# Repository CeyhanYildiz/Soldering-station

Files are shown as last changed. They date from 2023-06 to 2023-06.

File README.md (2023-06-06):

# My First Ever Self-Built Soldering Station

Presenting my inaugural creation: the self-built Soldering Station—a testament to my passion and determination.

## Features

- Meticulously assembled with top-quality components
- Seamlessly blends functionality and aesthetics
- Ergonomic handle for a comfortable grip
- Sleek control panel for intuitive operation
- State-of-the-art heating element for rapid and precise temperature control
- Integrated smart sensor system for safety and protection of delicate components

## Usage

Using this self-built soldering station fills me with immense satisfaction. It represents my commitment to craftsmanship and the pursuit of excellence.

## Journey and Inspiration

With my first creation, I have evolved from a novice to an artisan. This soldering station embodies innovation and creativity, empowering me to bring remarkable projects to life.

The journey has just begun, and I eagerly anticipate the countless achievements this exceptional tool will enable.

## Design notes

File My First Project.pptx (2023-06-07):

## My First Project : The Soldering Station

Ceyhan Yildiz

## Soldering Station : What to expect

1.0

Why this Project
Functionality
PCB
Case
Best Moments
Worst Moments
Cost

## Why this Project

2.0

Simplifying Complexity
Learning from Others

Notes: Simplifying Complexity : We mochten kiezen, Hard Time S1
Learning from Others : Same Project For exempel True is beter than SMD

## functionality

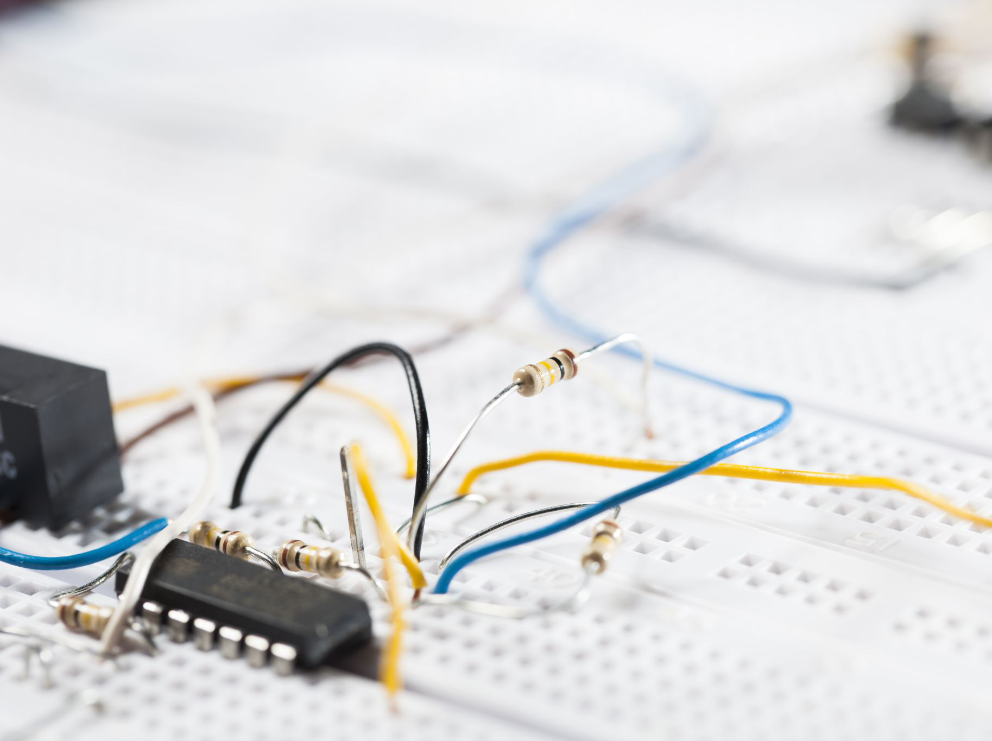
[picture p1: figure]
Electronics protoboard

- Soldering Iron
  - Components to be Soldered
- Power Supply Unit
- Temperature Control Mechanism

3.0

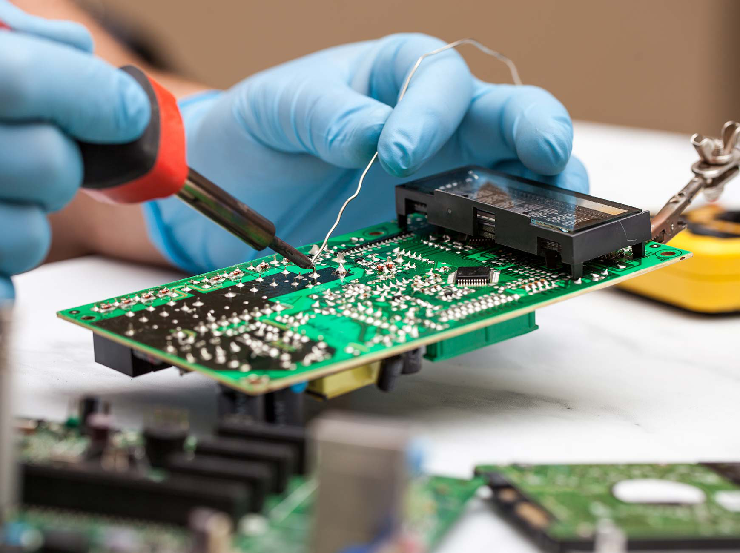
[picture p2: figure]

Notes: Soldering Iron:
Illustration of a soldering iron with a metal tip.
Components to be Soldered:
Small electronic components, such as resistors or capacitors, represented by symbols or icons.
Connection lines between the components.
Power Supply Unit:
Box representing the power supply unit.
Temperature Control Mechanism:
Rotary knob
Connection lines linking the temperature control mechanism to the soldering iron.
Soldering Process:
Illustration of the soldering iron touching the component leads and the circuit board.
Heat waves emanating from the soldering iron to indicate the heating process.
Melting solder represented by droplets or lines bonding the component leads and the circuit board.
Result:
Illustration of a completed solder joint with the components securely connected to the circuit board.

## PCB

- Schematics
  - Thermokoppel
  - Voeding
  - CPY
  - PBM
  - Display
- Manufactory
- Soldering

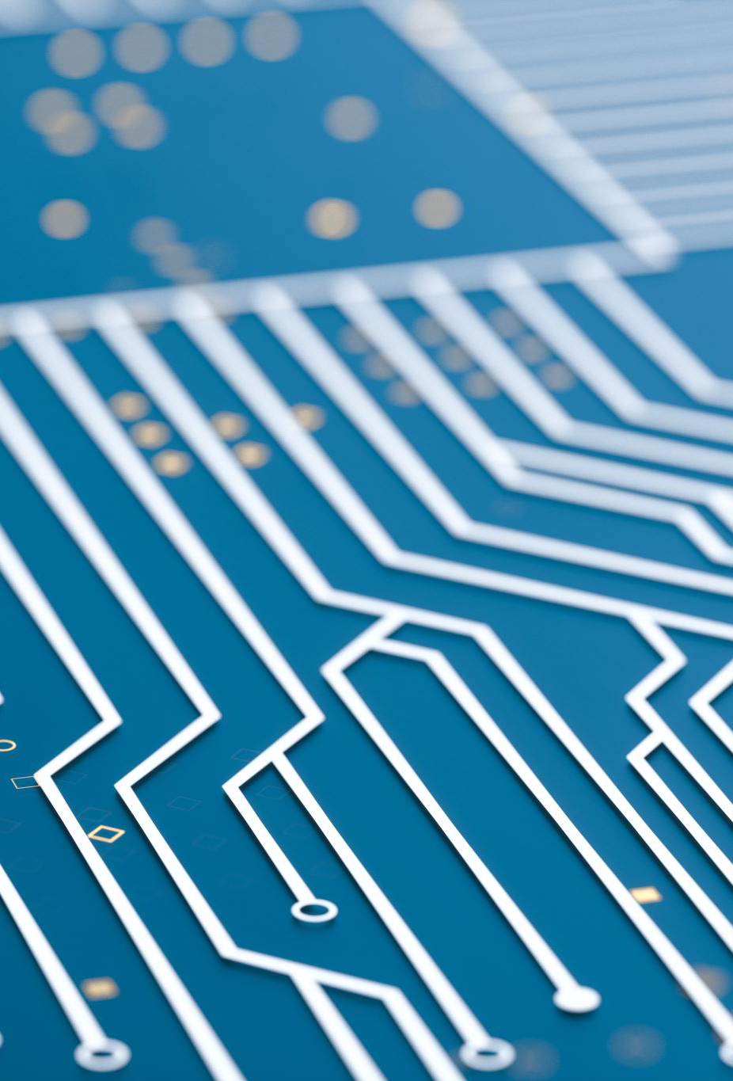
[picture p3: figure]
Een blauwe printplaat

4.0

## case design

5.0

Version 0.1

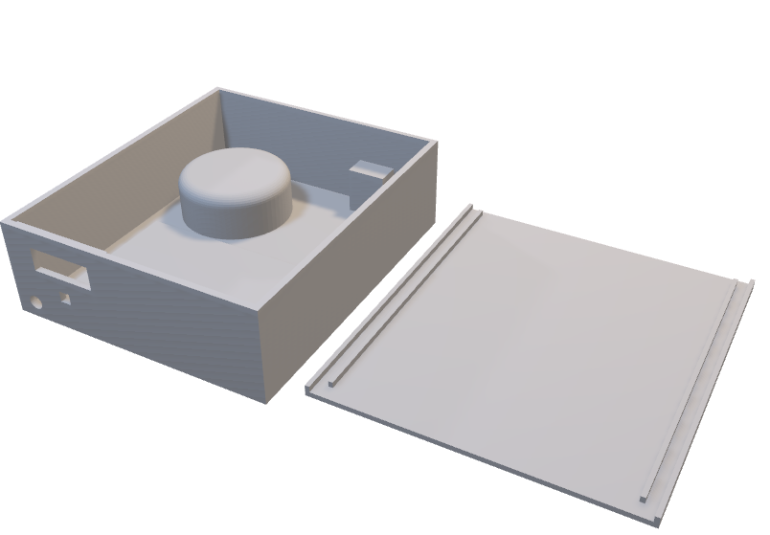
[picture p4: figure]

Version 0.0

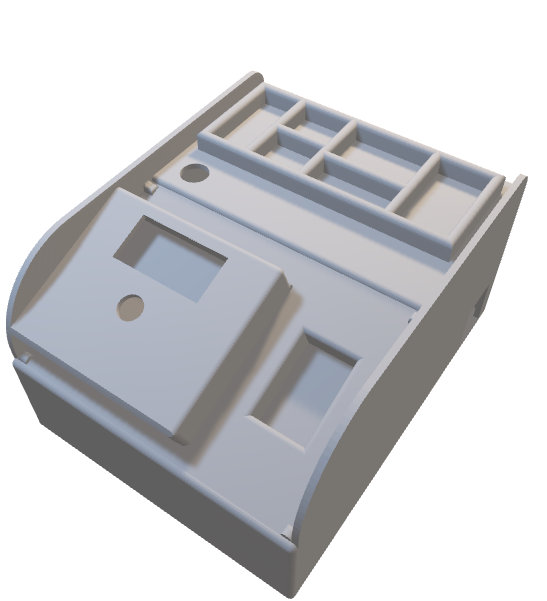
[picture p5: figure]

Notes: Lost hope
Did not gave up

## Best Moments

6.0

Learned
Ready for the NEXT

## Worst Moments

7.0

Price
Silkscreen
Timing
Learning
Incomplete

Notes: Not knowing the correct Prices
Silkscreen to small
pcb took to long to arrivé
Learing curve Altium Designer
Not done

## Cost Breakdown

- Components : €35
- PCB : €32
- Toroidal transformer : €25 – €40
Extra :
  - Display : €1,60
  - Case : €25
  - Soldering iron : €15
Total : €133,6 – €148,6

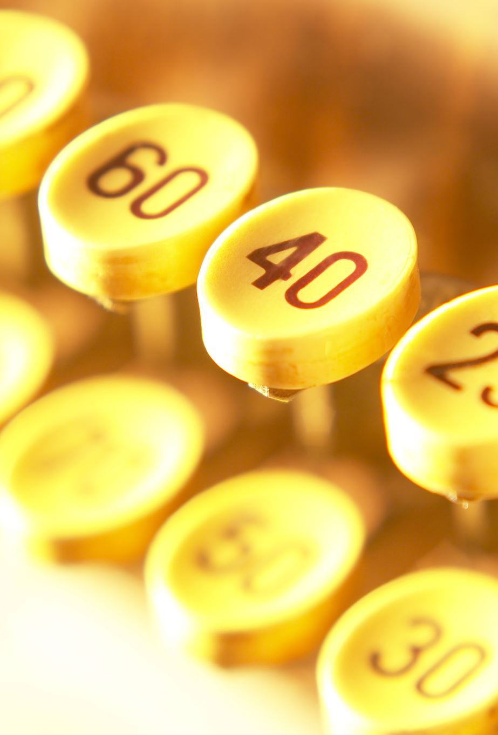
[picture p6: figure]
Antique cash register keys

8.0

## THANKS for your attentions

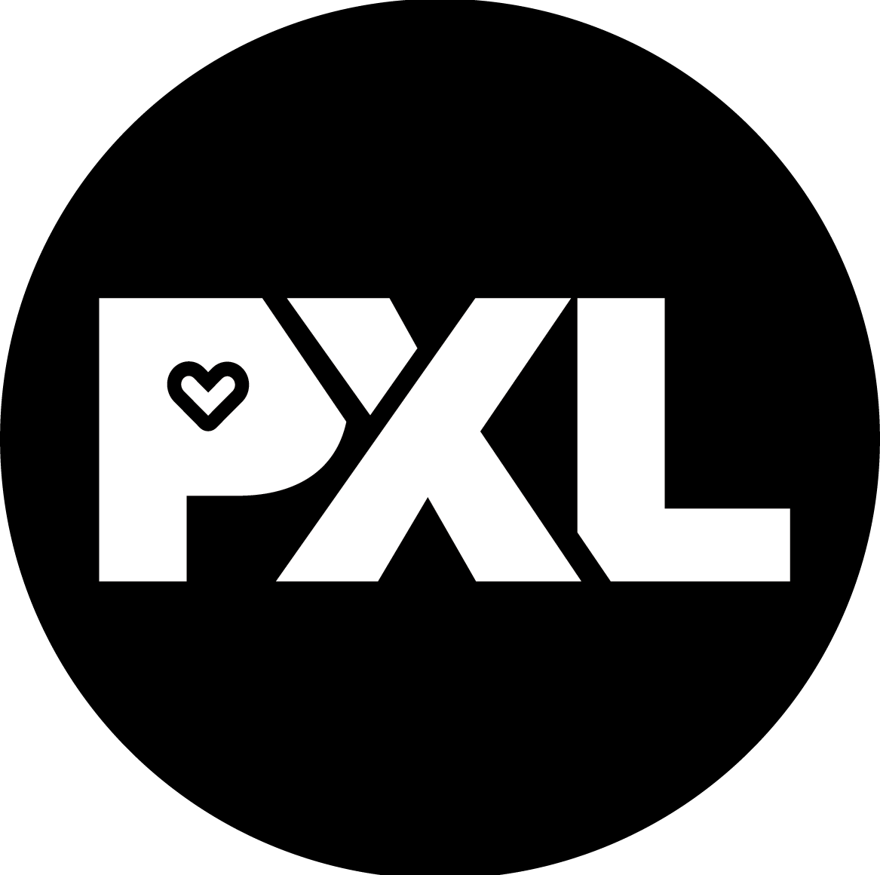
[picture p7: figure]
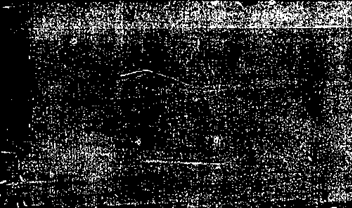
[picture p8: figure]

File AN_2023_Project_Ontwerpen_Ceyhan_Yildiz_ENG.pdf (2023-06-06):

# ELEKTRONICA-ICT

### Project Ontwerpen

# Soldering Station

Author Ceyhan Yildiz

## Content

ELECTRONICS-ICT | Project Design 2020-2021

## 1 Introduction

For my project I embarked on building a soldering station based on the blueprint provided by our lecturer ( Elektor ( ElektorMAG, 2021) ). The soldering station I created includes essential features such as a temperature control knob, soldering iron holder and a replaceable tip iron. These components enable precise temperature control during soldering tasks and provide a safe storage solution for the soldering iron.

While I consider my efforts in building the soldering station satisfactory. I do recognize that there is room for improvement. One aspect I identified for enhancement is the addition of a built-in smoke absorber for safety purposes. Implementing such a feature would help mitigate potential health risks associated with soldering fumes.

However, due to financial constraints, I was unable to fully complete the project as envisioned. Despite this limitation. I was able to gain valuable hands-on experience and expand my knowledge in soldering techniques and electronics assembly. Building a functional device from scratch was challenging but ultimately provided me with a deeper understanding of the entire process.

In conclusion, even though I didn't have sufficient funds to fully realize my project. I’m satisfied with the progress I made in constructing the soldering station. I now possess a valuable tool for future DIY (Do It Yourself) projects and have acquired valuable skills and knowledge along the way. Moving forward, I hope to continue improving my soldering station and explore additional projects in the field of electronics.

## 2 Material and methods

I consider myself quite lucky as one of my college mates made it incredibly easy for me to acquire the necessary components for a mere 35 euros. This stroke of fortune has paved the way for an exciting project or experiment. Let me introduce you to the components I now possess:

Resistors:

- 18 KΩ smd 805
- 1 MΩ smd 805
- 68 KΩ smd 805
- 5.6 KΩ smd 805
- 10 KΩ smd 805
- 100 Ω smd 805
- 10 MΩ smd 805
- 4.7 KΩ smd 805

Inductors:

- | L1 | smd 805
- | L2 | smd 2545

Capacitors:

- 4700 µF True hole D25xL25mm
- 10 µF smd D4XL5,4
- 100 nF | smd 805
- 100 µF | smd D8xL10mm
- 10 nF smd 805

Semiconductors:

- | 1N4007 | smd SOD-123Fl
- | Zener | smd SOD-123Fl
- | 1N14148 | smd SOD-123Fl
- | Bridge | smd TTF
- | BC847C | smd SOT-23
- | MOSFET-P | smd TO-252-2(DPAK)
- | BC857C | SOT-23
- | DC/DC | True hole
- MCP6002-E/MS MSOP-8
- Microcontroller TQFP-48
- | Relay | True hole
- IC2 7-segment smd SOP-20
- | Encoder | True hole

Please note that the following comments can also be found in the ElektorMAG magazine published in 2021 on page 34.

Smd ( Surface mount technology )

SOD ( Small Outline Diode )

TO ( Transistor Outline )

With these components, I can construct the soldering station that meets my specific needs. The resistors will help regulate lower the voltage, and the capacitors and inductors can assist with filtering and power supply stability. The semiconductors, including diodes and transistors, play crucial roles in controlling the heating element and managing the power flow.

The microcontroller will serve as the brain of the soldering station, enabling precise temperature control, user interface, and additional features such as temperature display and adjustable settings. The relay can be used for switching the heating element on and off, while the IC2 7-segment display driver will allow for temperature readout.

Overall, with these components, I have the foundation for building a functional and customized soldering station that will enhance my soldering projects with precise temperature control and additional features.

### 2.1 Flowchart

Below is a comprehensive flowchart outlining the sequential process for creating a project using Altium Designer. It encompasses the stages of case design and printing, PCB soldering, testing, and project assembly. This streamlined workflow offers a clear, step-by-step guide to ensure a successful project completion.

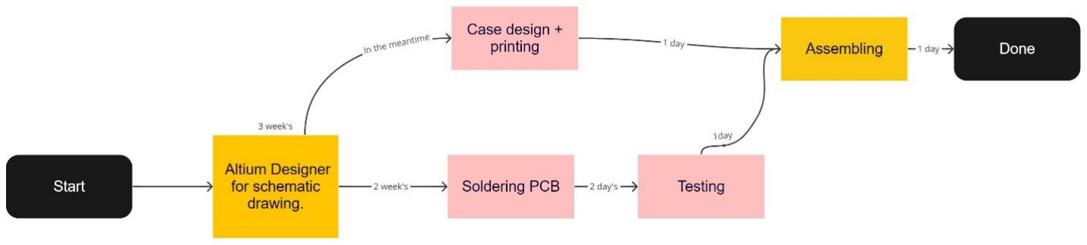
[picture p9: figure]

The process begins with the utilization of Altium Designer. A software tool for schematic drawing which is used for a duration of 3 weeks. During this time the schematic design for the PCB is meticulously created.

After successfully finalizing the schematic design I decided to collaborate with two other individuals who were also working on the same project. By combining our efforts and orders, we were able to leverage the benefits of a group purchase resulting in reduced shipping costs. As a result I only needed to pay 32 euros, significantly reducing the overall expenses.

During the waiting period of approximately two weeks for the PCB fabrication. I made efficient use of my time by focusing on designing and printing a customized case for the project. This approach allowed me to create a personalized case that perfectly matched the project's requirements ensuring both functionality and aesthetics were met. By capitalizing on this waiting period I ensured that every aspect of the project was optimized and met my high standards.

Once the PCB arrives from the manufacturer the next step is soldering. This involves carefully placing and soldering electronic components onto the PCB following the schematic design. Precision and attention to detail are vital during this phase.

Following the soldering process a dedicated 2-day period is allocated for testing the functionality of the assembled PCB. Various tests and inspections are conducted to ensure that the PCB operates as intended and meets the required specifications.

Once the PCB has successfully passed the testing phase the final step is assembling the project. The assembled PCB along with any other necessary components is integrated into the previously printed case.

### 2.2 Observed

During the construction of my project. I observed that certain students opted for a greater utilization of through-hole components as opposed to SMD’s. This strategic decision allowed them to assemble the PCB more effortlessly. In contrast, I encountered difficulties while attempting to incorporate a silkscreen onto my PCB design.

## 3 Results

Despite facing financial constraints, I managed to make significant progress on the project. I successfully soldered my PCB, demonstrating my skill and attention to detail in electronic circuitry. By meticulously assembling and connecting the components, I ensured the functionality and reliability of the PCB.

Regarding the 3D design, although I couldn't afford to print it, I dedicated my efforts to carefully drawing and refining the design. Paying attention to intricate details, I aimed to create an accurate representation of the envisioned object or prototype. While the physical manifestation was limited by financial circumstances, my commitment to the project is evident through the meticulous and thorough work put into the 3D design.

### 3.1 Case

During the course of my project, there came a pivotal moment when I confronted a disheartening realization: my existing design fell short of my lofty expectations. Rather than succumbing to discouragement, I chose to embrace the challenge head-on, harnessing my unwavering determination to create a remarkably enhanced 3D design. Refusing to be deterred by self-doubt, I swiftly crafted a brand-new case design, propelling myself beyond my previous endeavors and embarking on a relentless pursuit of an ideal outcome.

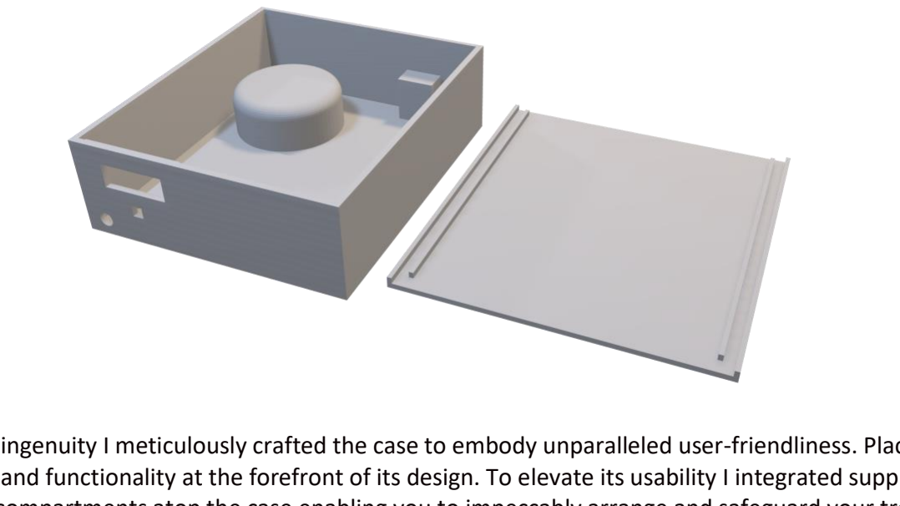
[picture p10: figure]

With utmost ingenuity I meticulously crafted the case to embody unparalleled user-friendliness. Placing convenience and functionality at the forefront of its design. To elevate its usability I integrated supplementary storage compartments atop the case enabling you to impeccably arrange and safeguard your treasured keepsakes. Moreover I attentively incorporated a compact holder specifically tailored to securely accommodate a sponge Providing you with effortless access to maintain the cleanliness of your soldering tip whenever the need arises. Through the implementation of these considerate features my intention was to guarantee a seamless and gratifying user experience for anyone utilizing the case.

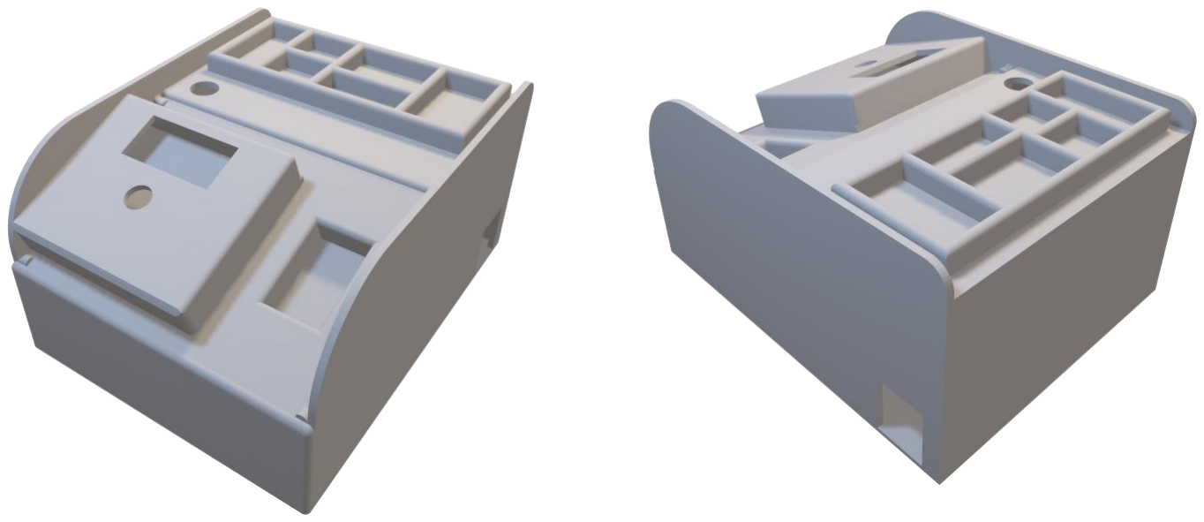
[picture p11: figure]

### 3.2 PCB

I am genuinely overjoyed with the final result of the PCB design. The meticulous attention to detail and careful consideration of every aspect have culminated in a truly remarkable outcome. One aspect that brings me immense satisfaction is the choice of color. The selected color not only adds a touch of elegance but also enhances the overall visual appeal of the board. Its subtle yet distinct presence exudes a sense of professionalism and sophistication elevating the board to a new level of aesthetic excellence. It brings me great pleasure to see that the design meets and even surpasses my expectations, a testament to the dedication and effort invested in this project. I am confident that this exceptional visual appeal will captivate the attention of anyone who encounters the PCB leaving a lasting impression of quality and craftsmanship.

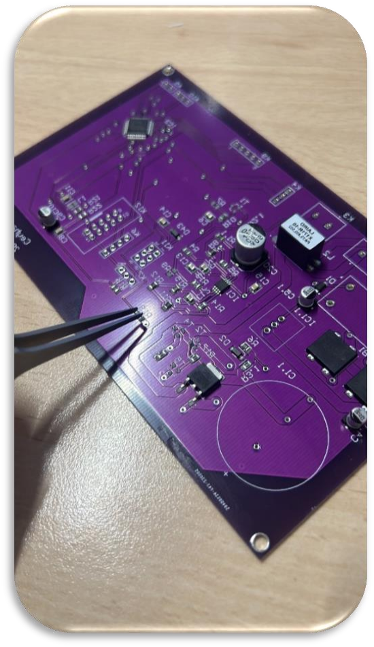
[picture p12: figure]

## 4 Discussion

### 4.1 First problem

Upon receiving my PCB from the manufacturer I encountered a few challenges that demanded my attention. One of the components specifically IC2 7-segment did not align correctly with its designated footprint. Regrettably the component was slightly oversized posing a significant obstacle. However I was fortunate to have the option of carefully bending the pins of the IC in order to solder it on top. Balancing precision with caution I had to exercise great care to avoid exerting excessive force that might result in damaging or breaking the pins.

### 4.2 Second problem

The learning curve for Altium Designer was undeniably steep requiring a significant investment of my time and effort. Over the course of three weeks I dedicated myself to mastering its intricacies. Despite the initial challenges I persevered and successfully acquired the necessary skills to navigate and utilize this powerful tool effectively. Looking ahead I am eager to employ Altium Designer to its fullest potential in my future projects. Its robust capabilities make it an invaluable asset and it would be a missed opportunity not to leverage its full range of features.

### 4.3 third problem

Initially I was unprepared for the substantial expenses associated with my project. I had hoped that the costs would be within the range of approximately 100 euros based on the information I had gathered. However upon observing that over 90% of students are spending upwards of 150 euros. It became apparent that a higher investment correlated with a greater likelihood of success. This realization emphasized the importance of allocating sufficient funds to increase my chances of achieving the desired outcome. While the unexpected cost may have caught me off guard. I now understand the significance of investing more in order to maximize my potential for success.

## 5 Reference list

Elektor Mag 507 MAY/JUNE 2021

ELEKTORMAGAZINE.COM

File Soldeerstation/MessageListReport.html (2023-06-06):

Altium customize

# Message List

Date: | | 31-3-2023
Time: | | 08:35:28
Elapsed Time: | | 00:00:00

Class | Document | Source | Message | Time | Date | No.
[Warning] | Thermokoppel.SchDoc | Compiler | Component IC1 Dual_Opamp has unused sub-part(s) (2). | 08:35:23 | 31-3-2023 | 1
[Warning] | Thermokoppel.SchDoc | Compiler | Component IC2 Dual_Opamp has unused sub-part(s) (1). | 08:35:23 | 31-3-2023 | 2
[Warning] | Thermokoppel.SchDoc | Compiler | Floating No ERC at 5200mil,4800mil | 08:35:23 | 31-3-2023 | 3
[Warning] | Thermokoppel.SchDoc | Compiler | Floating No ERC at 5200mil,5400mil | 08:35:23 | 31-3-2023 | 4
[Warning] | Thermokoppel.SchDoc | Compiler | Global Power-Object +5 at 8500mil,4100mil has been reduced to local level by presence of port at 8800mil,3800mil | 08:35:23 | 31-3-2023 | 5
[Info] | Soldeerstation.PrjPcb | Compiler | Compile successful, no errors found. | 08:35:23 | 31-3-2023 | 6

Back to top

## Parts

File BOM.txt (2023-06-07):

Dankzij de inzet van een van mijn collega's heeft hij veel tijd besteed aan het zorgvuldig bestellen van de juiste componenten, en dat voor een ongelooflijk lage prijs van slechts 35 euro.

MEER INFO IN " Componenten.xlsx "

Resistors:

- 18 KΩ
- 1 MΩ
- 68 KΩ
- 5.6 KΩ
- 10 KΩ
- 100 Ω
- 10 MΩ
- 4.7 KΩ

Inductors:

- L1
- L2

Capacitors:

- 4700 µF
- 10 µF
- 100 nF
- 100 µF
- 10 nF

Semiconductors:

- 1N4007
- Zener
- 1N14148
- Bridge
- BC847C
- MOSFET-P
- BC857C
- DC/DC
- MCP6002-E/MS
- Microcontroller
- Relay
- IC2 7-segment
- Encoder

De PCB heeft me 32 euro gekost.

Ik heb verder niets betaald omdat ik niet bereid was om meer dan 100 euro uit te geven aan dit project. Het printen van de behuizing is niet gelukt omdat ik geen printer tot mijn beschikking had (of ik kon niet gemakkelijk naar de makerspace gaan vanwege ongunstige tijden).

Op een maandag had meneer Hilven het lokaal open gelaten, maar hij had ons minder dan 24 uur van tevoren op de hoogte gesteld. Als hij ons eerder had laten weten, had ik mijn spullen kunnen pakken en kunnen komen.

Helaas is mijn project niet afgerond.

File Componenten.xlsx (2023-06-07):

 | MFR No. | Package
Resistors
18 Kohm | https://www.lcsc.com/product-detail/Chip-Resistor-Surface-Mount_VO-SCR0805J18K_C3017916.html | 805 | 3
1 Mohm | https://www.lcsc.com/product-detail/Chip-Resistor-Surface-Mount_FOJAN-FRC0805J105-TS_C2907302.html | 805 | 1
68 Kohm | SCR0805J68K | 805 | 1
5,6 Kohm | SCR0805J5K6 | 805 | 4
10 Kohm | https://www.lcsc.com/product-detail/Chip-Resistor-Surface-Mount_UNI-ROYAL-Uniroyal-Elec-0805W8F1002T5E_C17414.html | 805 | 6
100 ohm | https://www.lcsc.com/product-detail/Chip-Resistor-Surface-Mount_UNI-ROYAL-Uniroyal-Elec-0805W8F1000T5E_C17408.html | 805 | 3
10 Mohm | https://www.lcsc.com/product-detail/Chip-Resistor-Surface-Mount_FOJAN-FRC0805J106TS_C2930232.html | 805 | 1
4,7 Kohm | https://www.lcsc.com/product-detail/Chip-Resistor-Surface-Mount_FOJAN-FRC0805J472-TS_C2907326.html | 805 | 6
Inductor
L1 | https://www.lcsc.com/product-detail/Power-Inductors_KOHERelec-PMI201214S-100M_C2922559.html | 805 | 1
L2 | https://www.mouser.be/ProductDetail/875-CM | 2545 | 1
Capacitor
4700 uF | https://www.lcsc.com/product-detail/Aluminum-Electrolytic-Capacitors-Leaded_CX-Dongguan-Chengxing-Elec-GR478M050O25RR0VZ2FPD_C45663.html | D25xL25mm plugin | 1
10 uF | https://www.lcsc.com/product-detail/Aluminum-Electrolytic-Capacitors-SMD_ST-Semtech-CS1E100M-CRC54_C98750.html | D4XL5,4 | 3
100 nF |  | 805 | 6
100 uF | https://www.lcsc.com/product-detail/Aluminum-Electrolytic-Capacitors-SMD_Nichicon-UWT1H101MNL1GS_C445063.html | SMD,D8xL10mm | 2
10 nF | https://www.lcsc.com/product-detail/Multilayer-Ceramic-Capacitors-MLCC-SMD-SMT_CCTC-TCC0805X7R103M500DT_C376921.html | 805 | 7
Semiconductors
1n4007 | A7 | SOD-123Fl | 1
Zener | https://www.lcsc.com/product-detail/Zener-Diodes_Shandong-Jingdao-Microelectronics-BZT52C5V1_C353516.html | SOD-123Fl | 1
1n14148 | https://www.lcsc.com/product-detail/Switching-Diode_Shandong-Jingdao-Microelectronics-1N4148W_C115103.html | SOD-123Fl | 1
Brug | https://www.lcsc.com/product-detail/Bridge-Rectifiers_MDD-Microdiode-Electronics-TTR8MF_C712546.html | TTF | 2
BC847C | https://www.lcsc.com/product-detail/Bipolar-Transistors-BJT_SALLTECH-BC847C_C3027113.html | SOT-23 | 3
MOSFET-P | https://www.lcsc.com/product-detail/MOSFETs_UTC-Unisonic-Tech-UTT18P10L-TN3-R_C84900.html | TO-252-2(DPAK) | 1
BC857C | https://www.lcsc.com/product-detail/Bipolar-Transistors-BJT_Jiangsu-Changjing-Electronics-Technology-Co-Ltd-BC857_C2139.html | SOT-23 | 1
DC/DC | https://www.mouser.be/ProductDetail/580-OKI78SR5-1.5W36C | ? | 1
MCP6002-E/MS | https://www.mouser.be/ProductDetail/Microchip-Technology-Atmel/MCP6002-E-MS?qs=huzeVNXgovXv0kPjGdVLUA%3D%3D | MSOP-8 | 1
Mircocontroler | https://www.mouser.be/ProductDetail/556-ATMEGA4809-AU | TQFP-48 | 1
relay | https://www.mouser.be/ProductDetail/TE-Connectivity-PB/RT424005F?qs=8wHch9UpSvaH%252B%252BmsSCbj0Q%3D%3D | ? | 1
IC2 7seg | https://www.lcsc.com/product-detail/LED-Display-Drivers_TM-Shenzhen-Titan-Micro-Elec-TM1637-TA2007_C5337160.html | SOP-20 | 1
encoder | https://www.lcsc.com/product-detail/Rotary-Encoders_BOURNS-PEC11R-4220F-S0012_C143817.html | ? | 1

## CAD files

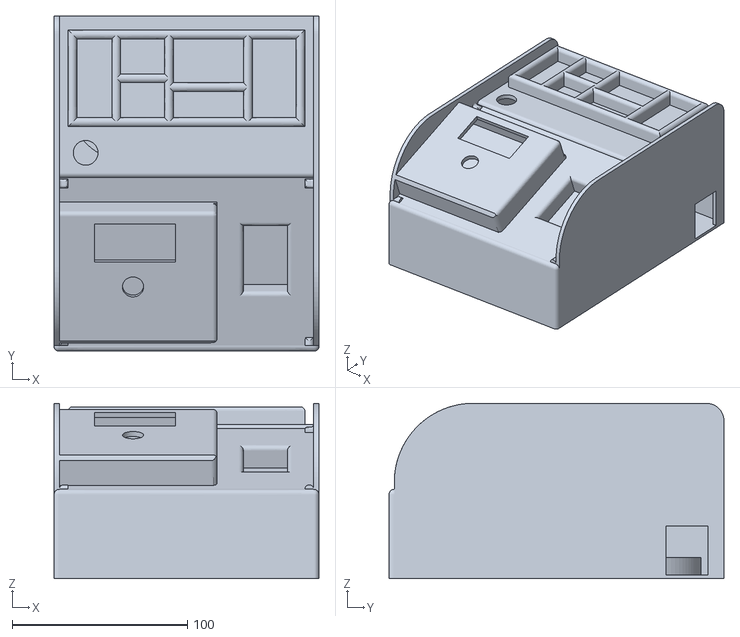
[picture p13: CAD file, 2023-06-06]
Case/Second_version_case.stl
151.0 x 191.0 x 100.0

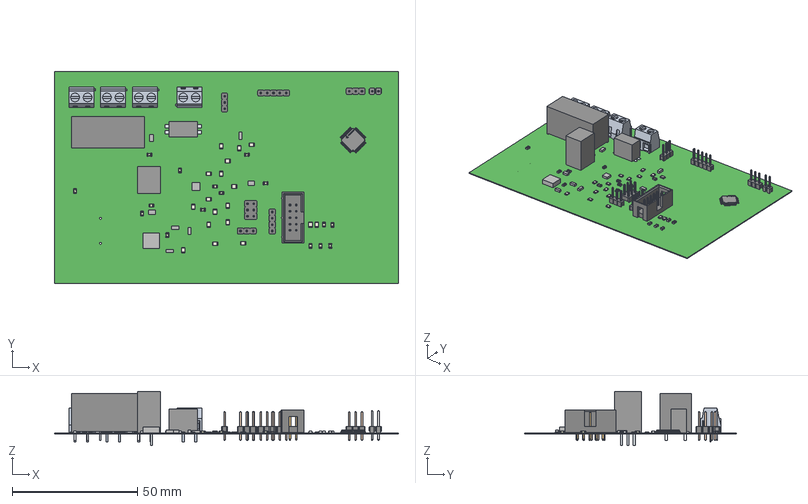
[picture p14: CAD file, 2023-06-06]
pcb/Soldeer.step
137.3 x 84.5 x 21.6 mm
Extruded x 63
Cap_KEMET_C0805C472J3HAC_eec x 48
Pins
6120xx21621_PIN x 10
6130xx21121_PIN x 6
6130xx11121_PIN x 18
c-282836-2-h-3d x 4
M20-999-MOULD
M20-999-PIN x 2
Harwin Logo Yury
pins
logo
Leads x 3

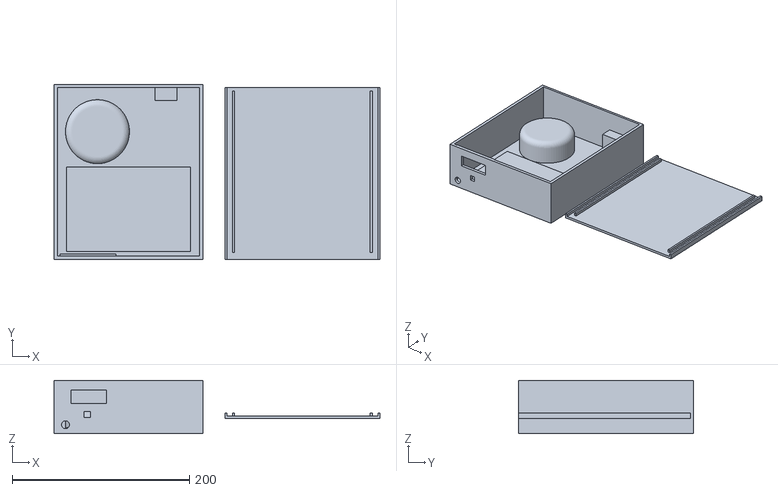
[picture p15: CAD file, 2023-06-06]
Case/First_version_case.stl
367.5 x 197.0 x 60.0

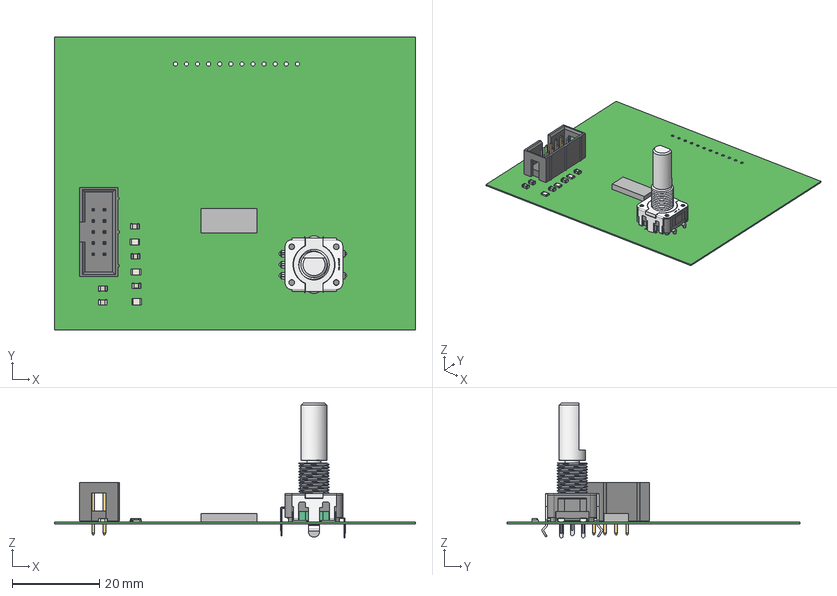
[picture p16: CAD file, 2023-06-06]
pcb/Displayd.step
82.7 x 67.2 x 30.9 mm
Extruded x 10
6120xx21621_PIN x 10
Bourns
Cap_KEMET_C0805C472J3HAC_eec x 15

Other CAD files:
Case/Better_case.f3d

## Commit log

2023-06-06 Soldering Station
    [Best_Case_In_The_World v2.stl, Better_case.f3d, CPU.SchDoc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]
2023-06-06 Name Update
    [First_version_case.stl, Second_version_case.stl]
2023-06-07 Power Point added
2023-06-07 Update BOM
    [Componenten.xlsx]
